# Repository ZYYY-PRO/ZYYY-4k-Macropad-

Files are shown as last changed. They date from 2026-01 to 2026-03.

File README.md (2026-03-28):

# ZYYYPAD
All the files that are required to produce the pcb is opensource

<b> https://youtu.be/lbP1HDdJELI video BTW

---

Visit here for the Billing of Material: **Parts.md**

---

Project Log: ZYYY 4k-Macropad

| Mentor: Mr. Porczek
Official Timeline: Sept 2025 – Jan 23, 2026

---
# I. The Research & Design Phase
## SEPTEMBER 2025 - Research & Logic

    Started deep-dive research into mechanical keyboard mounting styles (Gasket vs. Tray).

    Analyzed the RP2040 Datasheet to understand pin mapping.

    Studied the Keyboard Matrix logic to plan the 4x5 layout.

## OCTOBER 2025 - Electrical Engineering

    Began schematic design in KiCad.

    Integrated the MCU, USB-C components, and the Rotary Encoder into the circuit.

    Finalized the diode-per-switch logic to ensure NKRO (N-Key Rollover).

## NOVEMBER 2025 - PCB Layout & Routing

    Spent the month physically routing traces on the PCB.

    Designed the "ZYYY 4KPAD" aesthetic silkscreen for the back of the board.

## DECEMBER 2025 - 3D Mechanical Modeling

    Began 3D modeling the enclosure in Autodesk Fusion.

    Designed custom "scooped" ergonomic keycaps and the encoder knob.
---
# II. The Crisis & Pivot
## JANUARY 8, 2026 - The SSD Disaster

    22:58 PM: Catastrophic hardware failure. The laptop fell and broke; the internal SSD fried.

    Result: Loss of all original KiCad files, Fusion models, and raw video footage.

## JANUARY 9, 2026 - Emergency Mentorship

    Met with Mr. Porczek to assess the damage.

    He helped boost confidence and helped plan the "Challenging 2-Week Completion" recovery phase.

    Switched all project files to a dedicated External SSD for safety.

## JANUARY 12 - 15, 2026 - Rapid Re-Design

    Redid the entire KiCad schematic and PCB layout from memory.

    Attempted to order parts from JLCPCB; discovered RP2040 and Component Shortfalls.

    Decision: Pivoted to a full 3D-printed functional prototype to meet the school deadline.
---
# III. Production & Final Sprint
## JANUARY 16, 2026 - Fusion Redux

    Remodelled the entire case and keycap set in Fusion to optimize for 3D printing.

## JANUARY 17, 2026 - Start of Manufacturing

    Started mass-printing parts on the Bambu Lab P2S.

    Began the Video Editing Phase in DaVinci Resolve, reconstructing the narrative of the project.

## JANUARY 18, 2026 - 3D Printing & Recording

    Printed the bottom frame and 20 individual keycaps.

    Recorded "B-Roll" footage of the printing process using the Insta360 Ace Pro 2.

## JANUARY 19, 2026 - Assembly & Demo Recording

    Final physical assembly: Fitting switches and keycaps into the frames.

    Recorded functional tests, including the volume knob and video editing macros.

## JANUARY 20 - 21, 2026 - Non-Stop Video Editing

    16-hour sessions in DaVinci Resolve.

    Synced the "Friday Night Funkin" gameplay footage to demonstrate the device's use cases.

    Voice-over for videos.

## JANUARY 22, 2026 - Final Polish & Canva Prep

    Added meme-overlays, 2017-style music transitions, and final project credits.

    Compiled all files, source code, and images into the final Canva Presentation.

## JANUARY 23, 2026 - Final Presentation & Upload

    Morning: Presented the 4K-Macropad live in class. Demonstrated the rotary encoder and editing shortcuts.

    Afternoon: Final video upload and GitHub repository push.
---
#  Project officially marked as SEMI-COMPLETED.
# Stay tune for part 2

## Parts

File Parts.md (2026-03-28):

## Parts needed to solder the PCB
### Main Bottom Components:


### Top Components: 




### Switches **Need X2**


---

## Required Settings



---


---


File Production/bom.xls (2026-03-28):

JLCPCB BOM Tool - BOM Matching
BOM name：bom-JLCPCB Assembly Order.xlsx |  |  | Download Time：2026-03-28 12:42:51 |  |  |  | * Our matching results are updated in real-time, but stock and prices may change. If it's been over 24 hours, please re-match before placing your order.
PCB Assembled Qty：5 |  |  | Est. Total Price：10.4083
Your BOM |  |  |  |  | Matched Parts |  |  |  |  |  |  | Order Information
Top Designator | Bottom Designator | Comment | Footprint | JLCPCB Part # | Matches | Part # | Manufacturer | Footprint | Description | Category | Warning | JLCPCB Part # | Product link | Lib Type | Qty | Source | Total Price ($)
 | C1,C11,C5,C7,C8 | 1u | 0402 |  | Select by System | CL05A105KA5NQNC | Samsung Electro-Mechanics | 0402 | 1uF 25V X5R ±10% 0402 Multilayer Ceramic Capacitors MLCC - SMD/SMT ROHS | Multilayer Ceramic Capacitors MLCC - SMD/SMT |  | C52923 | https://jlcpcb.com/partdetail/53938-CL05A105KA5NQNC/C52923 | Basic | 20 | 20 JLCPCB | 0.08
 | C10,C12,C13,C14,C15,C18,C2,C3,C4,C6,C9 | 100n | 0402 |  | Select by System | CL05B104KO5NNNC | Samsung Electro-Mechanics | 0402 | 100nF 16V X7R ±10% 0402 Multilayer Ceramic Capacitors MLCC - SMD/SMT ROHS | Multilayer Ceramic Capacitors MLCC - SMD/SMT |  | C1525 | https://jlcpcb.com/partdetail/1877-CL05B104KO5NNNC/C1525 | Basic | 32 | 32 JLCPCB | 0.0416
 | C16,C17 | 30pf | 0402 |  | Select by System | 0402CG300J500NT | FH (Guangdong Fenghua Advanced Tech) | 0402 | 30pF 50V C0G ±5% 0402 Multilayer Ceramic Capacitors MLCC - SMD/SMT ROHS | Multilayer Ceramic Capacitors MLCC - SMD/SMT |  | C1570 | https://jlcpcb.com/partdetail/1922-0402CG300J500NT/C1570 | Extended | 20 | 20 JLCPCB | 0.024
 | D10,D11,D12,D13,D14,D15,D16,D17,D18,D19,D2,D20,D21,D3,D4,D5,D6,D7,D8,D9 | Diode/Diddy | D_SOD-123 |  | Select by System | 1N4148W | Jiangsu Changjing Electronics Technology Co., Ltd. | SOD-123 | 1.25V@150mA 100V 150mA 1uA@75V 2A 4ns 500mW Independent SOD-123 Switching Diodes ROHS | Switching Diodes |  | C2099 | https://jlcpcb.com/partdetail/2456-1N4148W/C2099 | Extended | 52 | 52 JLCPCB | 0.4836
 | F1 | 700mA | 0402 |  | Select by System | BSMD0402L-035 | BHFUSE | 0402 | -40℃~+85℃ 0.65mm 0.6mm 1.15mm 100ms 350mA 40A 500mW 50mΩ 6V 700mA 700mΩ 0402 Resettable Fuses ROHS | Resettable Fuses |  | C914086 | https://jlcpcb.com/partdetail/BHFUSE-BSMD0402L035/C914086 | Extended | 5 | 5 JLCPCB | 1.139
 | FB1 | 100Ohm@100MHz | 0402 |  | Select by System | BLM15AG121SN1D | Murata Electronics | 0402 | 1 120Ω@100MHz 190mΩ 550mA ±25% 0402 Ferrite Beads ROHS | Ferrite Beads |  | C85812 | https://jlcpcb.com/partdetail/MurataElectronics-BLM15AG121SN1D/C85812 | Extended | 20 | 20 JLCPCB | 0.14
 | J1 | USB_C_Receptacle_USB2.0_16P | USB_C_Receptacle_GCT_USB4105-xx-A_16P_TopMnt_Horizontal |  | Select by Customer | USB4105-GF-A | Global Connector Technology | SMD | -40℃~+85℃ 1 12P 48V 5A Black Female Surface Mount, Right Angle Type-C USB 2.0 SMD USB Connectors ROHS | USB Connectors |  | C3020560 | https://jlcpcb.com/partdetail/3542626-USB4105_GFA/C3020560 | Extended | 2 | 2 JLCPCB | 2.015
 | J2 | JST-1.00mm4Pin | JST_SH_SM04B-SRSS-TB_1x04-1MP_P1.00mm_Horizontal |  | Select by System | SM04B-SRSS-TB(LF)(SN) | JST | SMD,P=1mm,卧贴 | -25℃~+85℃ 1 1A 1mm 1x4P 2.9mm 4 4.32mm 4P 50V 6mm Auxiliary Solder Pin Copper alloy PA SH Surface Mount, Right Angle Tin UL94V-0 White SMD,P=1mm,卧贴 Wire To Board Connector ROHS | Wire To Board Connector |  | C160404 | https://jlcpcb.com/partdetail/JST-SM04B_SRSS_TB_LF_SN/C160404 | Extended | 5 | 5 JLCPCB | 1.044
 | R1,R2 | 22 | 0402 |  | Unconfirmed | 0402WGF220JTCE | UNI-ROYAL(Uniroyal Elec) | 0402 | -55℃~+155℃ 22Ω 50V 62.5mW Thick Film Resistor ±1% ±100ppm/℃ 0402 Chip Resistor - Surface Mount ROHS | Chip Resistor - Surface Mount | 1.The comment (0402WGF220JTCE) of this part does not match the one (22) provided in your BOM. Please confirm; | C25092 | https://jlcpcb.com/partdetail/25835-0402WGF220JTCE/C25092 | Basic | 20 | 20 JLCPCB | 0.016
 | R3,R8 | 1k | 0402 |  | Unconfirmed | 0402WGF1001TCE | UNI-ROYAL(Uniroyal Elec) | 0402 | -55℃~+155℃ 1kΩ 50V 62.5mW Thick Film Resistor ±1% ±100ppm/℃ 0402 Chip Resistor - Surface Mount ROHS | Chip Resistor - Surface Mount | 1.The comment (0402WGF1001TCE) of this part does not match the one (1k) provided in your BOM. Please confirm; | C11702 | https://jlcpcb.com/partdetail/12256-0402WGF1001TCE/C11702 | Basic | 20 | 20 JLCPCB | 0.014
 | R4,R5 | 5.1k | 0402 |  | Unconfirmed | 0402WGF5101TCE | UNI-ROYAL(Uniroyal Elec) | 0402 | -55℃~+155℃ 5.1kΩ 50V 62.5mW Thick Film Resistor ±1% ±100ppm/℃ 0402 Chip Resistor - Surface Mount ROHS | Chip Resistor - Surface Mount | 1.The comment (0402WGF5101TCE) of this part does not match the one (5.1k) provided in your BOM. Please confirm; | C25905 | https://jlcpcb.com/partdetail/26648-0402WGF5101TCE/C25905 | Basic | 20 | 20 JLCPCB | 0.016
 | R6,R7,R9 | 10k | 0402 |  | Unconfirmed | 0402WGF1002TCE | UNI-ROYAL(Uniroyal Elec) | 0402 | -55℃~+155℃ 10kΩ 50V 62.5mW Thick Film Resistor ±1% ±100ppm/℃ 0402 Chip Resistor - Surface Mount ROHS | Chip Resistor - Surface Mount | 1.The comment (0402WGF1002TCE) of this part does not match the one (10k) provided in your BOM. Please confirm; | C25744 | https://jlcpcb.com/partdetail/26487-0402WGF1002TCE/C25744 | Basic | 20 | 20 JLCPCB | 0.016
 | SW10,SW11,SW12,SW13,SW14,SW15,SW16,SW17,SW18,SW19,SW2,SW20,SW21,SW3,SW4,SW5,SW6,SW7,SW8,SW9 | Switch | SW_MX_HS_CPG151101S11_1u |  | Unconfirmed | HX-3x6x2.5-X SMD tact Switch | hanxia | SMD,6x3.5mm | -25℃~+70℃ 2.5N 2.5mm 250V 3.6mm 30,000 cycles 50mA 6mm No SMD(SMT) Tab SPST Square Button Surface Mount,Vertical White Without Bracket SMD,6x3.5mm Tactile Switches ROHS |  | 1.The comment (HX-3x6x2.5-X SMD tact Switch) of this part does not match the one (Switch) provided in your BOM. Please confirm; | C49234125 | https://jlcpcb.com/partdetail/C49234125 | Extended | 0 | 0 JLCPCB | 0
 | U2 | USBLC6-2SC6 | SOT-23-6 |  | Select by System | TPUSBLC6-2SC6 | TECH PUBLIC | SOT-23-6 | -55℃~+125℃ 0.35pF、0.8pF 100nA 15V 2 5V 9V ESD IEC 61000-4-2、IEC 61000-4-5、IEC 61000-4-4 SOT-23-6 ESD and Surge Protection (TVS/ESD) ROHS | ESD And Surge Protection (TVS/ESD) |  | C558442 | https://jlcpcb.com/partdetail/TECHPUBLIC-TPUSBLC62SC6/C558442 | Extended | 6 | 6 JLCPCB | 0.2772
 | U4 | 3.3VFixedRegulator | TSOT-23 |  | Select by System | AP2125N-3.3TRG1 | Diodes Incorporated | SOT-23 | -40℃~+85℃@(Ta) 1 3.3V 300mA 50uVrms 60uA 65dB@(1kHz) 65mV@(100mA) 6V Fixed Over Current Protection、Over Temperature Protection Positive SOT-23 Voltage Regulators - Linear, Low Drop Out (LDO) Regulators ROHS | Voltage Regulators - Linear, Low Drop Out (LDO) Regulators |  | C150715 | https://jlcpcb.com/partdetail/DiodesIncorporated-AP2125N_33TRG1/C150715 | Extended | 5 | 5 JLCPCB | 0.684
 | U5 | W25Q32JVSS | SOIC-8_5.3x5.3mm_P1.27mm |  | Unconfirmed | W25Q32JVSSIQ | Winbond Elec | SOIC-8-208mil | -40℃~+85℃ 100,000 cycles 133MHz 1uA 2.7V~3.6V 20 Years 32Mbit 3ms SPI SOIC-8-208mil NOR FLASH ROHS | NOR FLASH | 1.The comment (W25Q32JVSSIQ) of this part does not match the one (W25Q32JVSS) provided in your BOM. Please confirm; | C179173 | https://jlcpcb.com/partdetail/WinbondElec-W25Q32JVSSIQ/C179173 | Extended | 2 | 2 JLCPCB | 2.9814
 | Y1 | 12Mhz3225 | Crystal_SMD_3225-4Pin_3.2x2.5mm_HandSoldering |  | Select by Customer | ABM8-272-T3 | Abracon LLC | SMD3225-4P | -40℃~+85℃ 10pF 12MHz 50Ω Crystal Oscillator ±30ppm ±30ppm SMD3225-4P Crystals ROHS | Crystals |  | C20625731 | https://jlcpcb.com/partdetail/AbraconLLC-ABM8_272T3/C20625731 | Extended | 5 | 5 JLCPCB | 1.4365
 | U1 | RP2040 | QFN-56-1EP_7x7mm_P0.4mm_EP3.2x3.2mm |  | Select by System | RP2040 | Raspberry Pi | QFN-56-EP(7x7) | QFN-56-EP(7x7) Microcontrollers (MCU/MPU/SOC) ROHS | Microcontrollers (MCU/MPU/SOC) |  | C2961140 | https://jlcpcb.com/partdetail/RaspberryPi-RP2040/C2961140 | Extended | 2 | 0 JLCPCB | 0

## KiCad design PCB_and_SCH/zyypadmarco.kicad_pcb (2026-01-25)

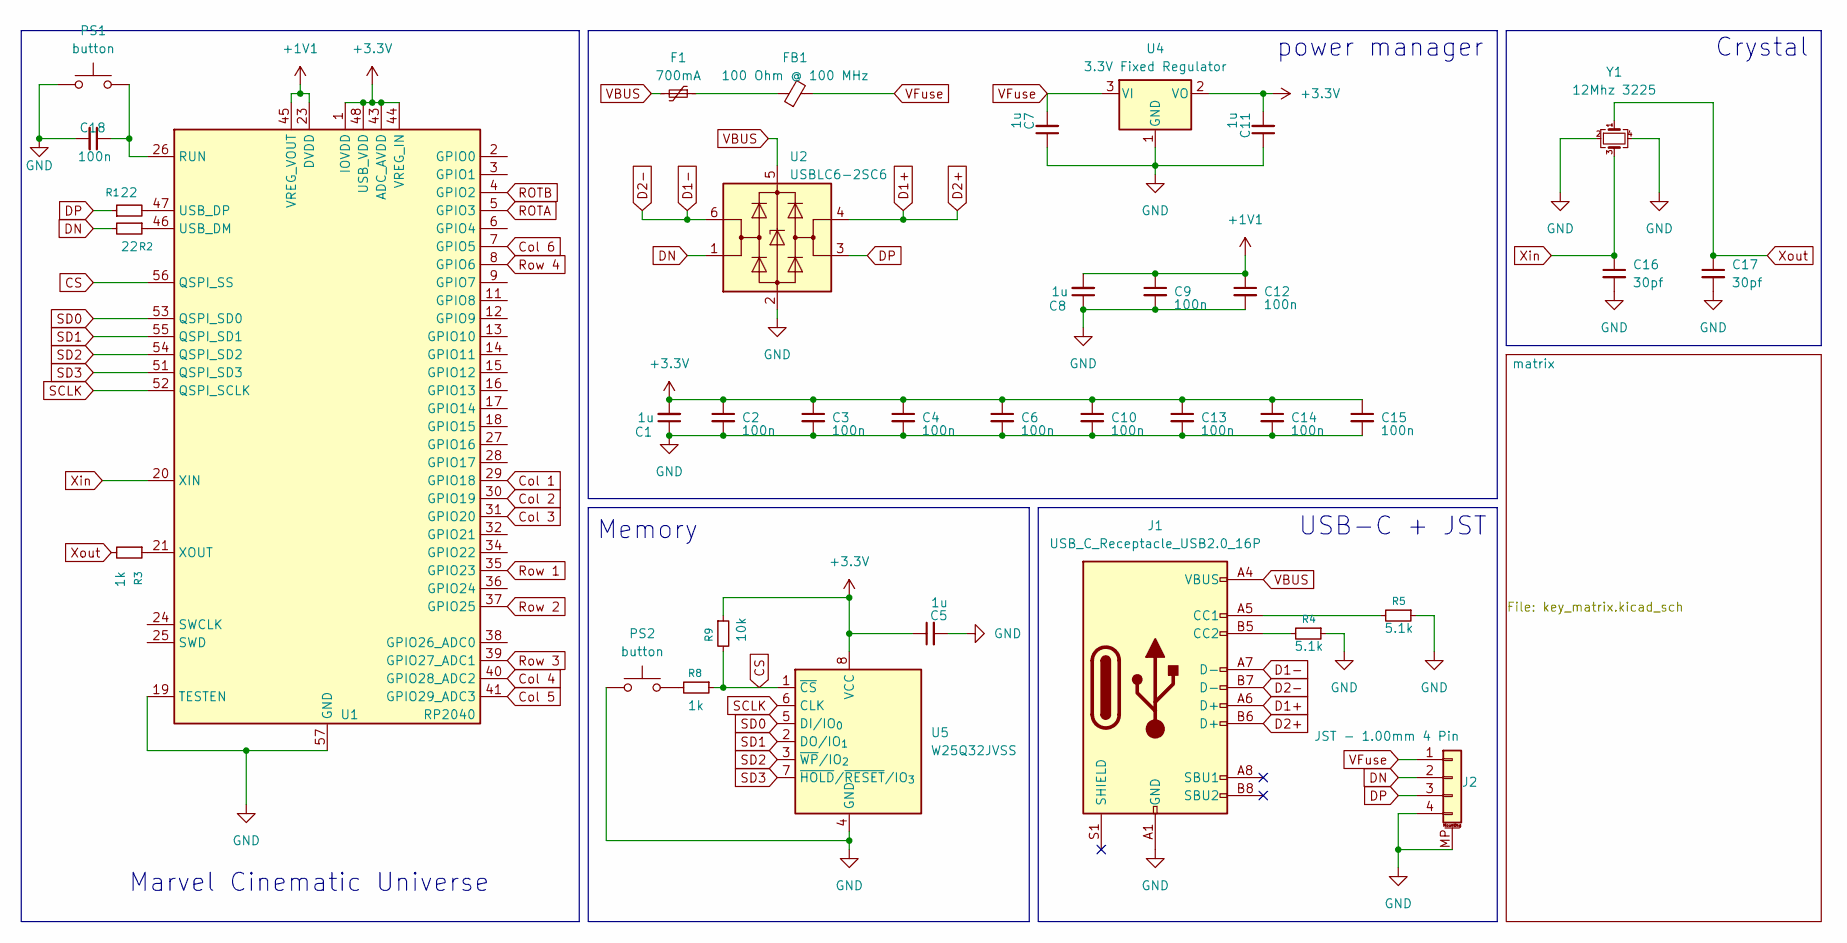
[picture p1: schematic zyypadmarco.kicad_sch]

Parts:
C1, C5, C7, C8, C11: 1u; C_0402_1005Metric; LCSC C52923
C2, C3, C4, C6, C9, C10, C12, C13, C14, C15, C18: 100n; C_0402_1005Metric; LCSC C1525
C16, C17: 30pf; C_0402_1005Metric
F1: 700mA; Fuse_0402_1005Metric; LCSC C914086
FB1: 100 Ohm @ 100 MHz; L_0402_1005Metric; LCSC C85812
J1: USB_C_Receptacle_USB2.0_16P; USB_C_Receptacle_GCT_USB4105-xx-A_16P_TopMnt_Horizontal
J2: JST - 1.00mm 4 Pin; JST_SH_SM04B-SRSS-TB_1x04-1MP_P1.00mm_Horizontal; LCSC C160404
PS1, PS2: button; SW_Push_1P1T_NO_E-Switch_TL3301NxxxxxG
R1, R2: 22; R_0402_1005Metric
R3, R8: 1k; R_0402_1005Metric
R4, R5: 5.1k; R_0402_1005Metric
R9: 10k; R_0402_1005Metric
U1: RP2040; QFN-56-1EP_7x7mm_P0.4mm_EP3.2x3.2mm
U2: USBLC6-2SC6; SOT-23-6; LCSC C558442
U4: 3.3V Fixed Regulator; TSOT-23; LCSC C150715
U5: W25Q32JVSS; SOIC-8_5.3x5.3mm_P1.27mm
Y1: 12Mhz 3225; Crystal_SMD_3225-4Pin_3.2x2.5mm_HandSoldering

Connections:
+1V1: C8.2, C9.1, C12.1, U1.23 (DVDD), U1.45 (VREG_VOUT), U1.50 (DVDD)
+3.3V: C1.2, C2.1, C3.1, C4.1, C5.1, C6.1, C10.1, C11.2, C13.1, C14.1, C15.1, R9.1, U1.1 (IOVDD), U1.10 (IOVDD), U1.22 (IOVDD), U1.33 (IOVDD), U1.42 (IOVDD), U1.43 (ADC_AVDD), U1.44 (VREG_IN), U1.48 (USB_VDD), U1.49 (IOVDD), U4.2 (VO), U5.8 (VCC); also elsewhere on the board
CS: R8.1, R9.2, U1.56 (QSPI_SS), U5.1 (~CS)
Col 1: U1.29 (GPIO18); also elsewhere on the board
Col 2: U1.30 (GPIO19); also elsewhere on the board
Col 3: U1.31 (GPIO20); also elsewhere on the board
Col 4: U1.40 (GPIO28_ADC2); also elsewhere on the board
Col 5: U1.41 (GPIO29_ADC3); also elsewhere on the board
Col 6: U1.7 (GPIO5); also elsewhere on the board
D1+: J1.A6 (D+), J1.B6 (D+), U2.4 (I/O2)
D1-: J1.A7 (D-), J1.B7 (D-), U2.6 (I/O1)
DN: J2.2, R2.2, U2.1 (I/O1)
DP: J2.3, R1.1, U2.3 (I/O2)
GND: C1.1, C2.2, C3.2, C4.2, C5.2, C6.2, C7.1, C8.1, C9.2, C10.2, C11.1, C12.2, C13.2, C14.2, C15.2, C16.2, C17.2, C18.2, J1.A1 (GND), J1.A12 (GND), J1.B1 (GND), J1.B12 (GND), J2.4, J2.MP (MountPin), PS1.1, PS2.1, R4.1, R5.1, U1.19 (TESTEN), U1.57 (GND), U2.2 (GND), U4.1 (GND), U5.4 (GND), Y1.2, Y1.4; also elsewhere on the board
unnamed: F1.1, FB1.1
unnamed: J1.A5 (CC1), R5.2
unnamed: J1.B5 (CC2), R4.2
unnamed: PS2.2, R8.2
unnamed: C18.1, PS1.2, U1.26 (RUN)
unnamed: R2.1, U1.46 (USB_DM)
unnamed: R1.2, U1.47 (USB_DP)
unnamed: R3.1, U1.21 (XOUT)
ROTA: U1.5 (GPIO3); also elsewhere on the board
ROTB: U1.4 (GPIO2); also elsewhere on the board
Row 1: U1.35 (GPIO23); also elsewhere on the board
Row 2: U1.37 (GPIO25); also elsewhere on the board
Row 3: U1.39 (GPIO27_ADC1); also elsewhere on the board
Row 4: U1.8 (GPIO6); also elsewhere on the board
SCLK: U1.52 (QSPI_SCLK), U5.6 (CLK)
SD0: U1.53 (QSPI_SD0), U5.5 (DI/IO_{0})
SD1: U1.55 (QSPI_SD1), U5.2 (DO/IO_{1})
SD2: U1.54 (QSPI_SD2), U5.3 (~WP/IO_{2})
SD3: U1.51 (QSPI_SD3), U5.7 (~HOLD/~RESET/IO_{3})
VBUS: F1.2, J1.A4 (VBUS), J1.A9 (VBUS), J1.B4 (VBUS), J1.B9 (VBUS), U2.5 (VBUS)
VFuse: C7.2, FB1.2, J2.1, U4.3 (VI)
Xin: C16.1, U1.20 (XIN), Y1.3
Xout: C17.1, R3.2, Y1.1

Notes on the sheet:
Memory
Marvel Cinematic Universe
power manager
USB-C + JST
Crystal

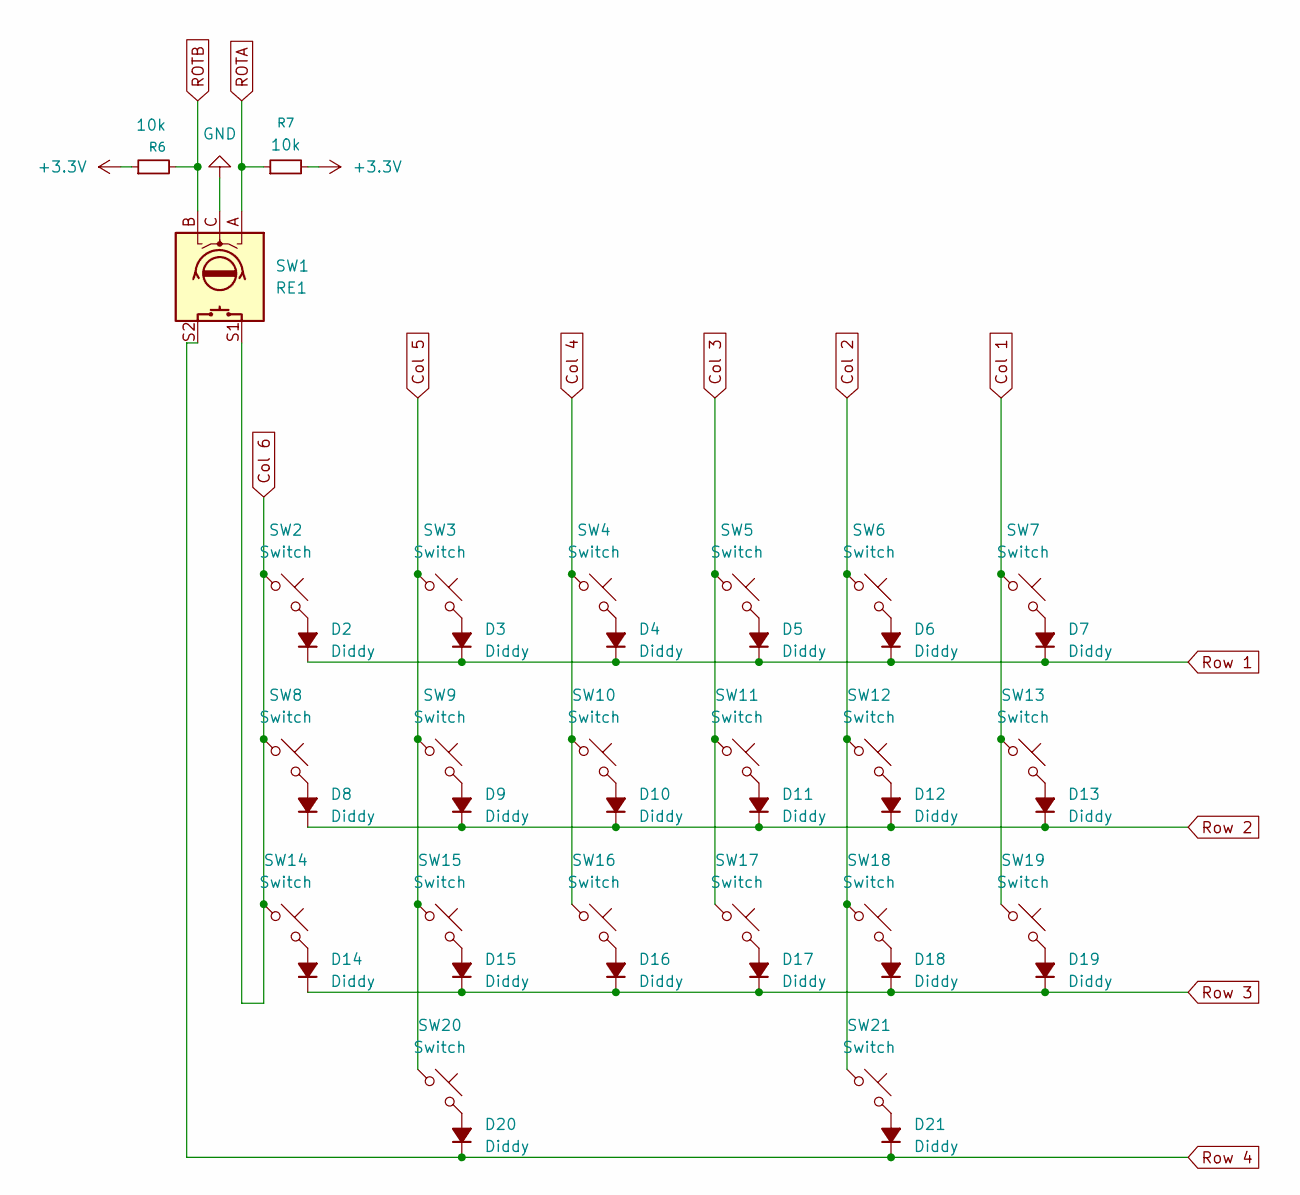
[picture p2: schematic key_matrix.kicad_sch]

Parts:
D2, D3, D4, D5, D6, D7, D8, D9, D10, D11, D12, D13, D14, D15, D16, D17, D18, D19, D20, D21: Diddy; D_SOD-123
R6, R7: 10k; R_0402_1005Metric
SW1: RE1; ROT_Alps_EC11E-Switch
SW2, SW3, SW4, SW5, SW6, SW7, SW8, SW9, SW10, SW11, SW12, SW13, SW14, SW15, SW16, SW17, SW18, SW19, SW20, SW21: Switch; SW_MX_HS_CPG151101S11_1u

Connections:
+3.3V: R6.1, R7.2; also elsewhere on the board
Col 1: SW7.1, SW13.1, SW19.1; also elsewhere on the board
Col 2: SW6.1, SW12.1, SW18.1, SW21.1; also elsewhere on the board
Col 3: SW5.1, SW11.1, SW17.1; also elsewhere on the board
Col 4: SW4.1, SW10.1, SW16.1; also elsewhere on the board
Col 5: SW3.1, SW9.1, SW15.1, SW20.1; also elsewhere on the board
Col 6: SW1.S1, SW2.1, SW8.1, SW14.1; also elsewhere on the board
GND: SW1.C; also elsewhere on the board
unnamed: D2.2 (A), SW2.2
unnamed: D3.2 (A), SW3.2
unnamed: D4.2 (A), SW4.2
unnamed: D5.2 (A), SW5.2
unnamed: D6.2 (A), SW6.2
unnamed: D7.2 (A), SW7.2
unnamed: D8.2 (A), SW8.2
unnamed: D9.2 (A), SW9.2
unnamed: D10.2 (A), SW10.2
unnamed: D11.2 (A), SW11.2
unnamed: D12.2 (A), SW12.2
unnamed: D13.2 (A), SW13.2
unnamed: D14.2 (A), SW14.2
unnamed: D15.2 (A), SW15.2
unnamed: D16.2 (A), SW16.2
unnamed: D17.2 (A), SW17.2
unnamed: D18.2 (A), SW18.2
unnamed: D19.2 (A), SW19.2
unnamed: D20.2 (A), SW20.2
unnamed: D21.2 (A), SW21.2
ROTA: R7.1, SW1.A; also elsewhere on the board
ROTB: R6.2, SW1.B; also elsewhere on the board
Row 1: D2.1 (K), D3.1 (K), D4.1 (K), D5.1 (K), D6.1 (K), D7.1 (K); also elsewhere on the board
Row 2: D8.1 (K), D9.1 (K), D10.1 (K), D11.1 (K), D12.1 (K), D13.1 (K); also elsewhere on the board
Row 3: D14.1 (K), D15.1 (K), D16.1 (K), D17.1 (K), D18.1 (K), D19.1 (K); also elsewhere on the board
Row 4: D20.1 (K), D21.1 (K), SW1.S2; also elsewhere on the board

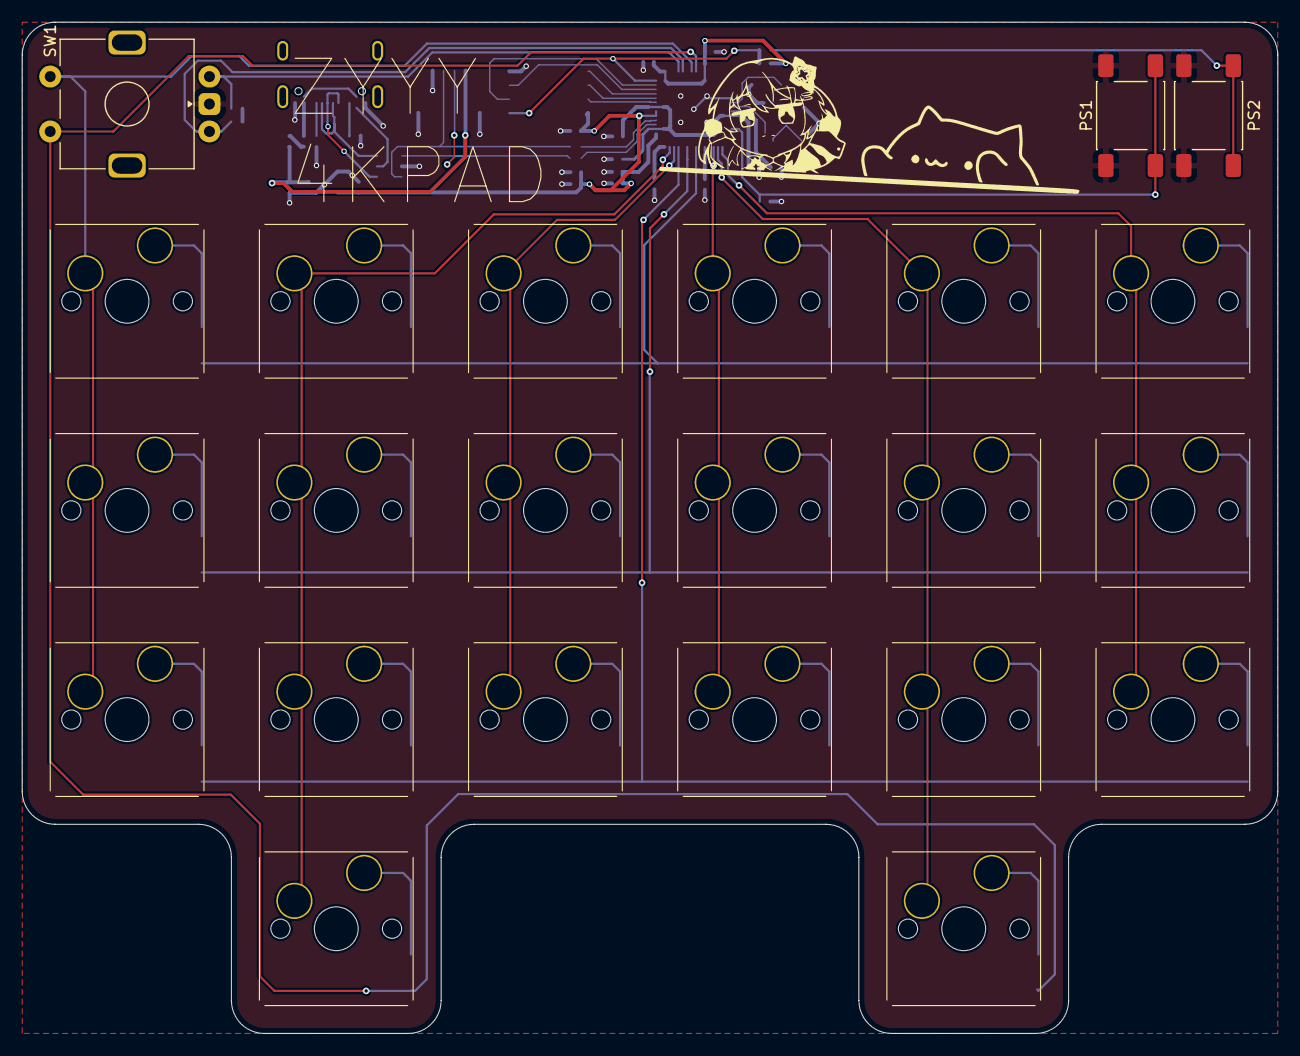
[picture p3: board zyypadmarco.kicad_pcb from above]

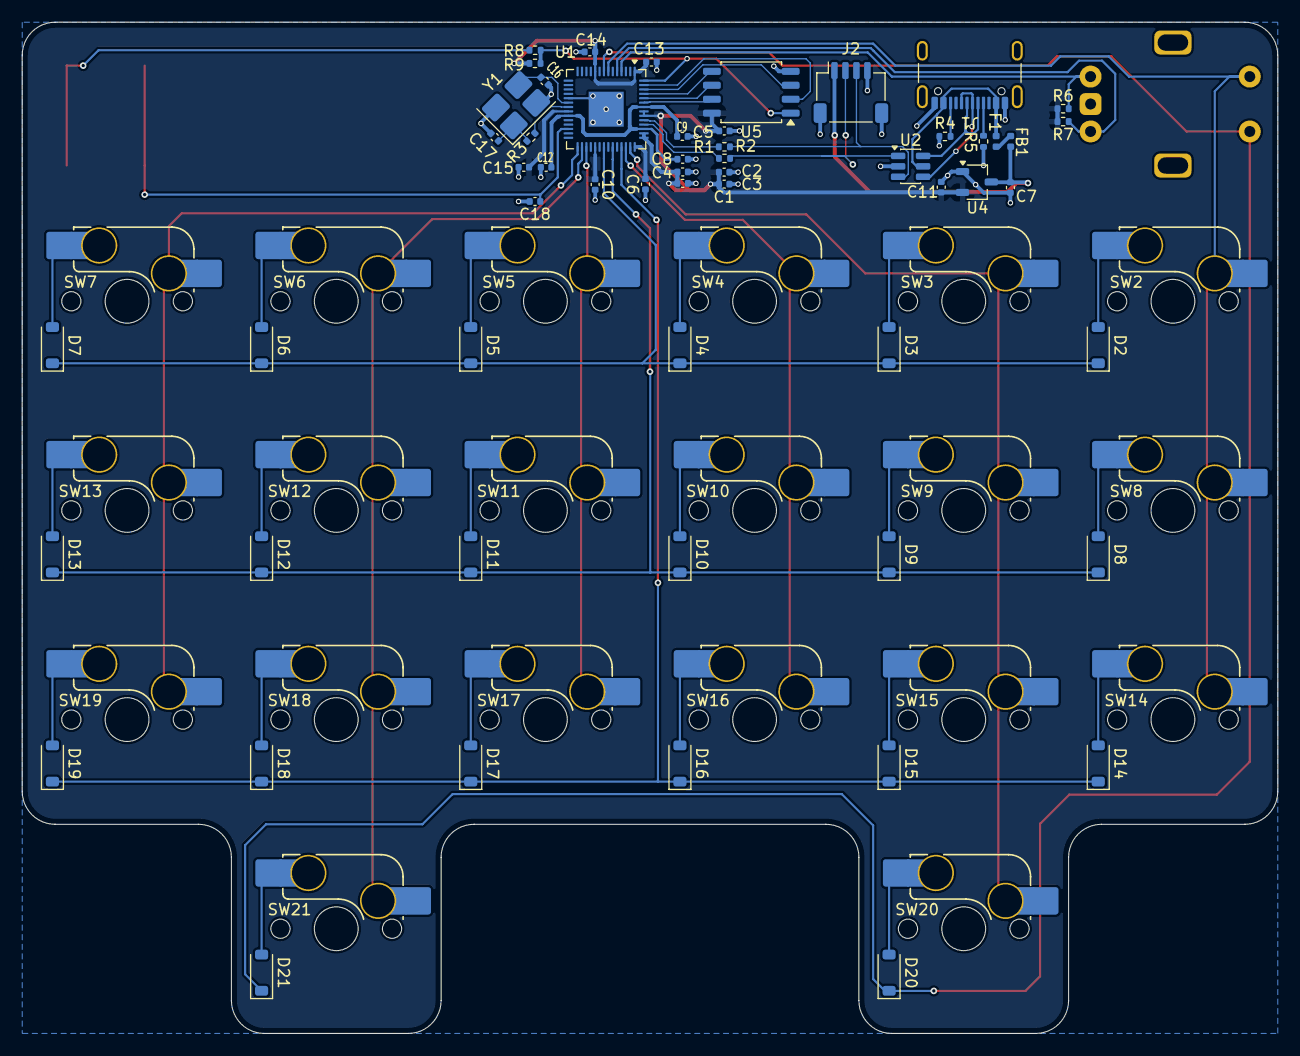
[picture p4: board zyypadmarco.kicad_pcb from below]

Board: 2 copper layers, 114.4 x 92.1 mm, 79 parts (76 on the bottom side), 57 nets.

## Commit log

2026-03-28 Update Parts.md with additional component images
    Added images and details for top components and switches needed for PCB soldering.
2026-03-28 gerber and stuff
    [bom.xls, positions.csv]
